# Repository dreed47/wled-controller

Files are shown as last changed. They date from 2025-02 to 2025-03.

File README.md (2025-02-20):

# WLED Controller (ESP32) - 4 Channels - Optional current and power monitoring

## Features

- 4 Channels
  - Max 25A total
  - Max 10A per channel
- Every channel has _independent_ current, power and voltage monitoring (using INA219)
- Sending power monitoring data to HomeAssistant via MQTT
- Seperate 3.3V low noise voltage regulator for audio section
- _**Optional:** INMP441 I2S Microphone with low noise power supply_
- Two versions of PCB esp32 dev kit and esp32 SMD
- This board requires a usermod for WLED for full support of all features including power monitoring.

## ESP32 Dev Kit Version

Interactive [BOM can be found here](https://rawcdn.githack.com/dreed47/wled-controller/main/bom/ibom.html).

### 3D Board view

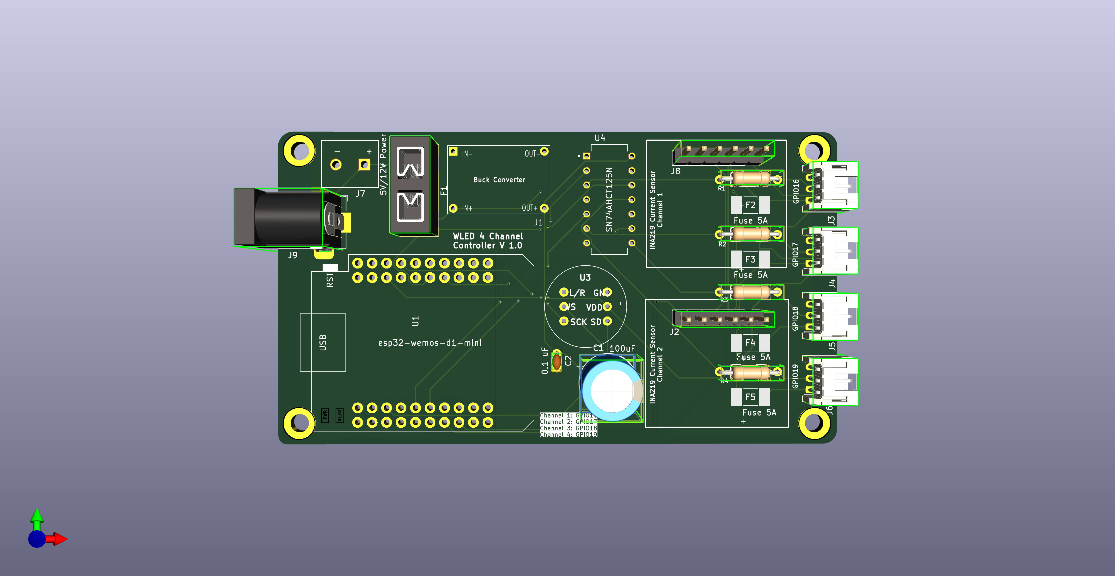
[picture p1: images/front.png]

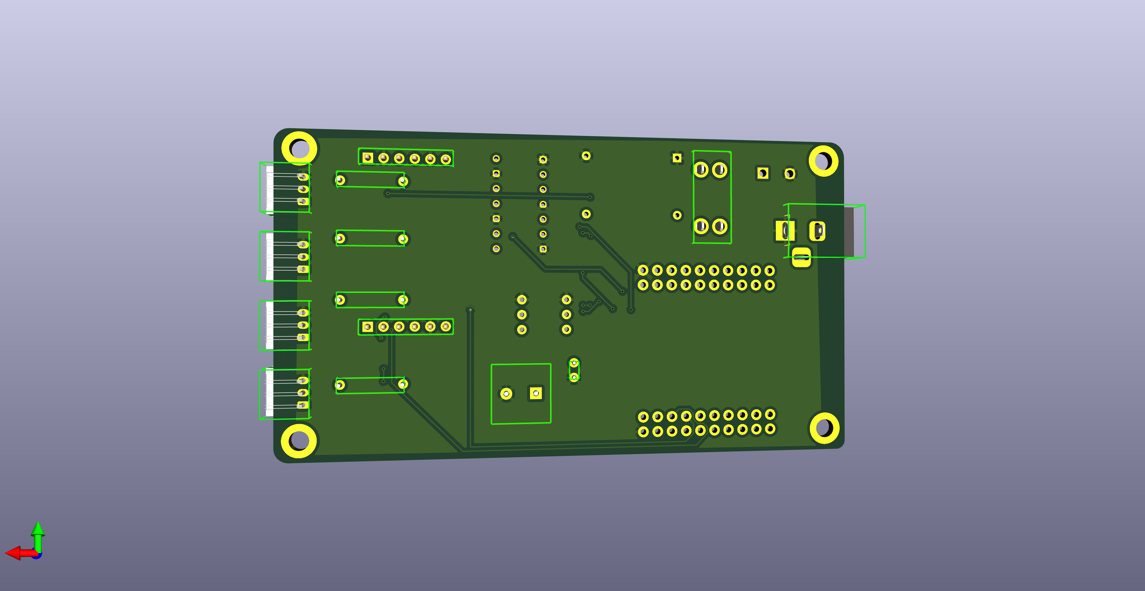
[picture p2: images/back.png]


### Board

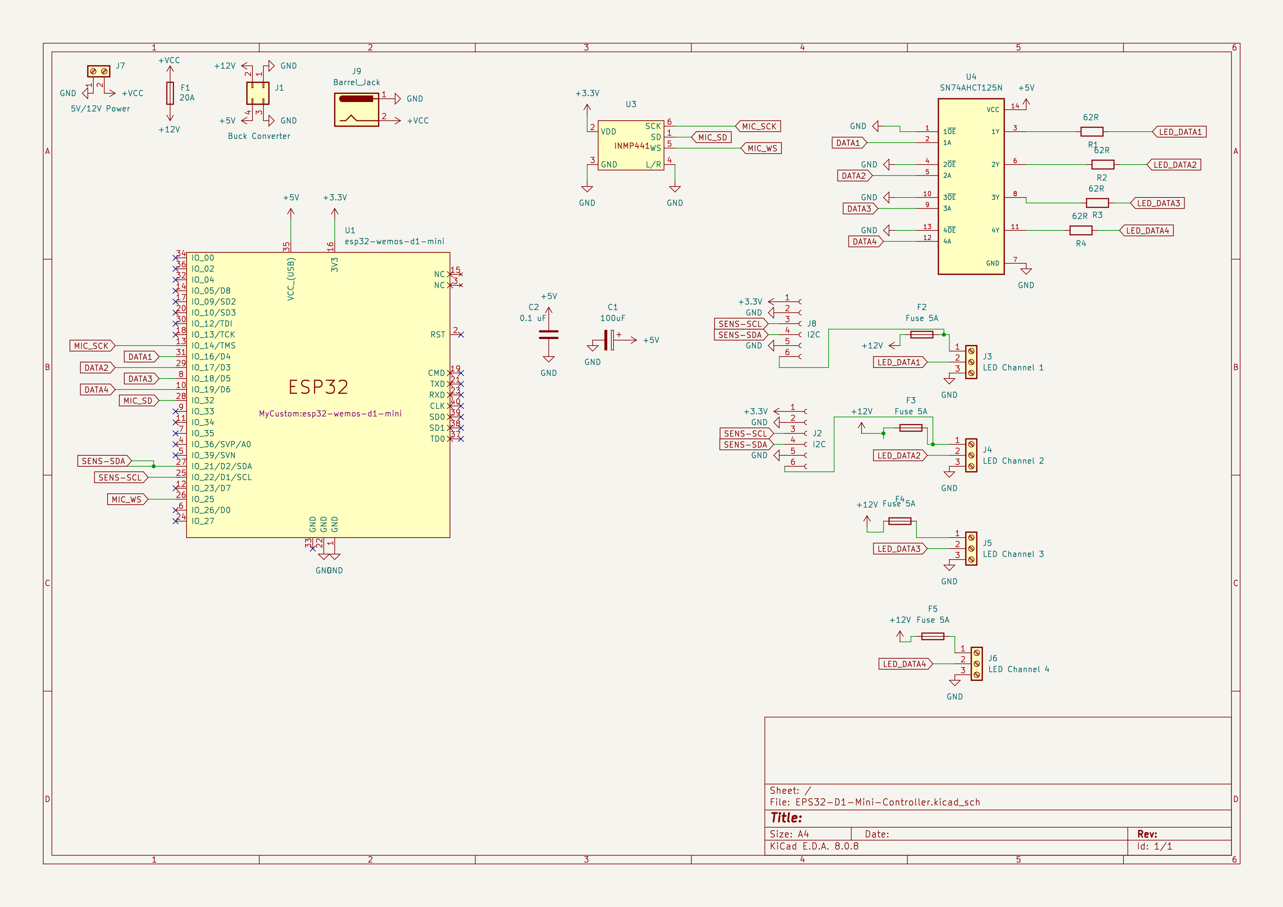
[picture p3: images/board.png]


## ESP32 SMD Version

Interactive [BOM can be found here](https://rawcdn.githack.com/dreed47/wled-controller/main/bom_smd/ibom.html).

### 3D Board view

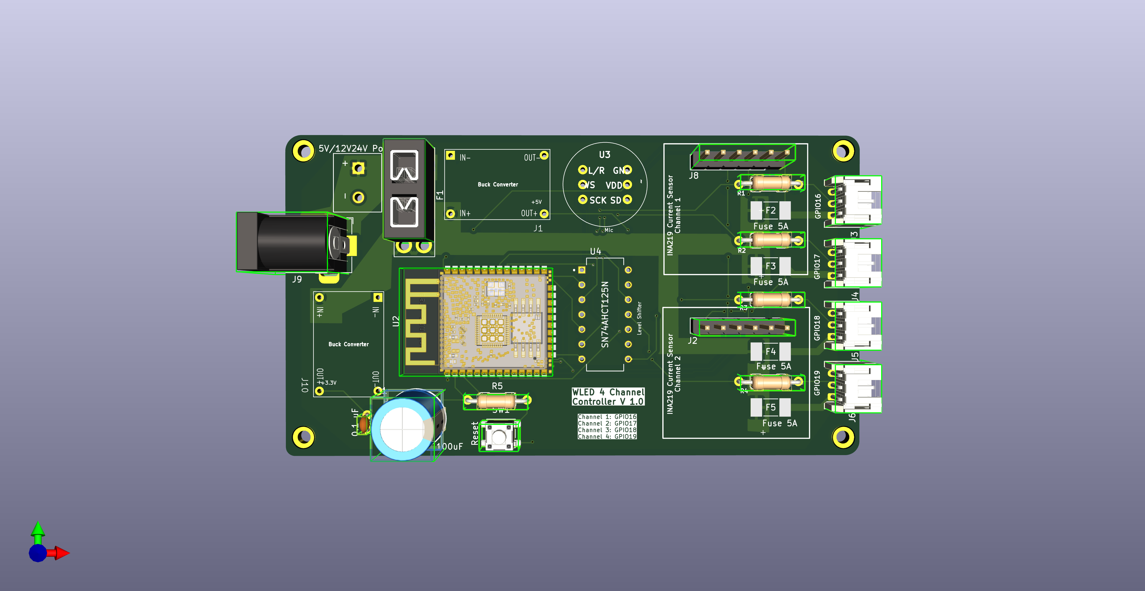
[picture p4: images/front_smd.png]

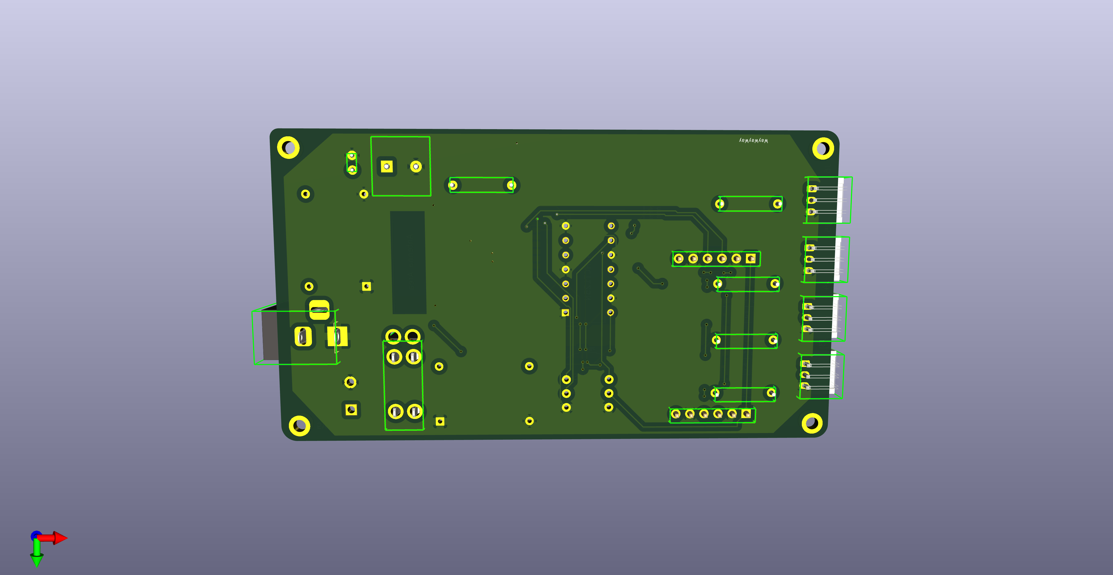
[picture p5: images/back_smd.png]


### Board

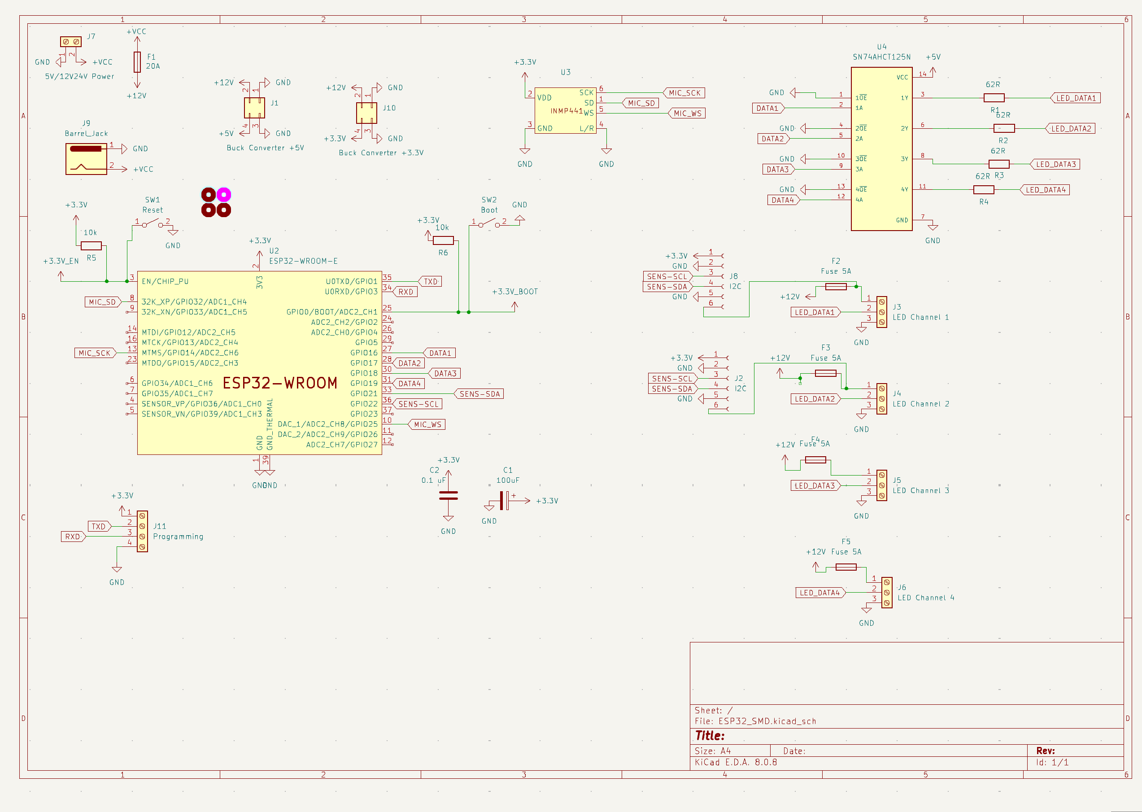
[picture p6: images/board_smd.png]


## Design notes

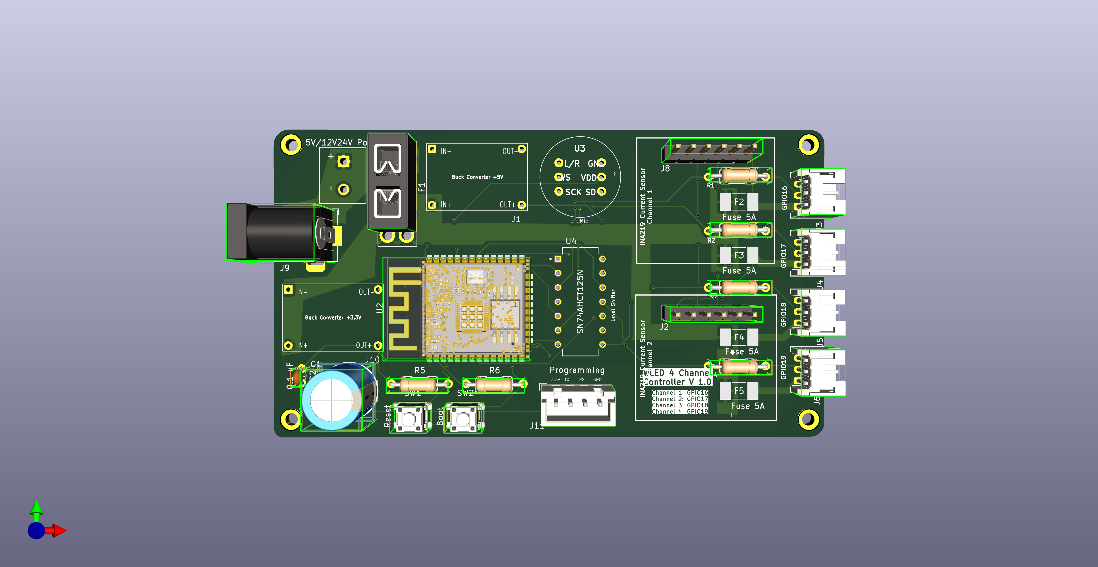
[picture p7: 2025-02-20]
images/ESP32_SMD.png

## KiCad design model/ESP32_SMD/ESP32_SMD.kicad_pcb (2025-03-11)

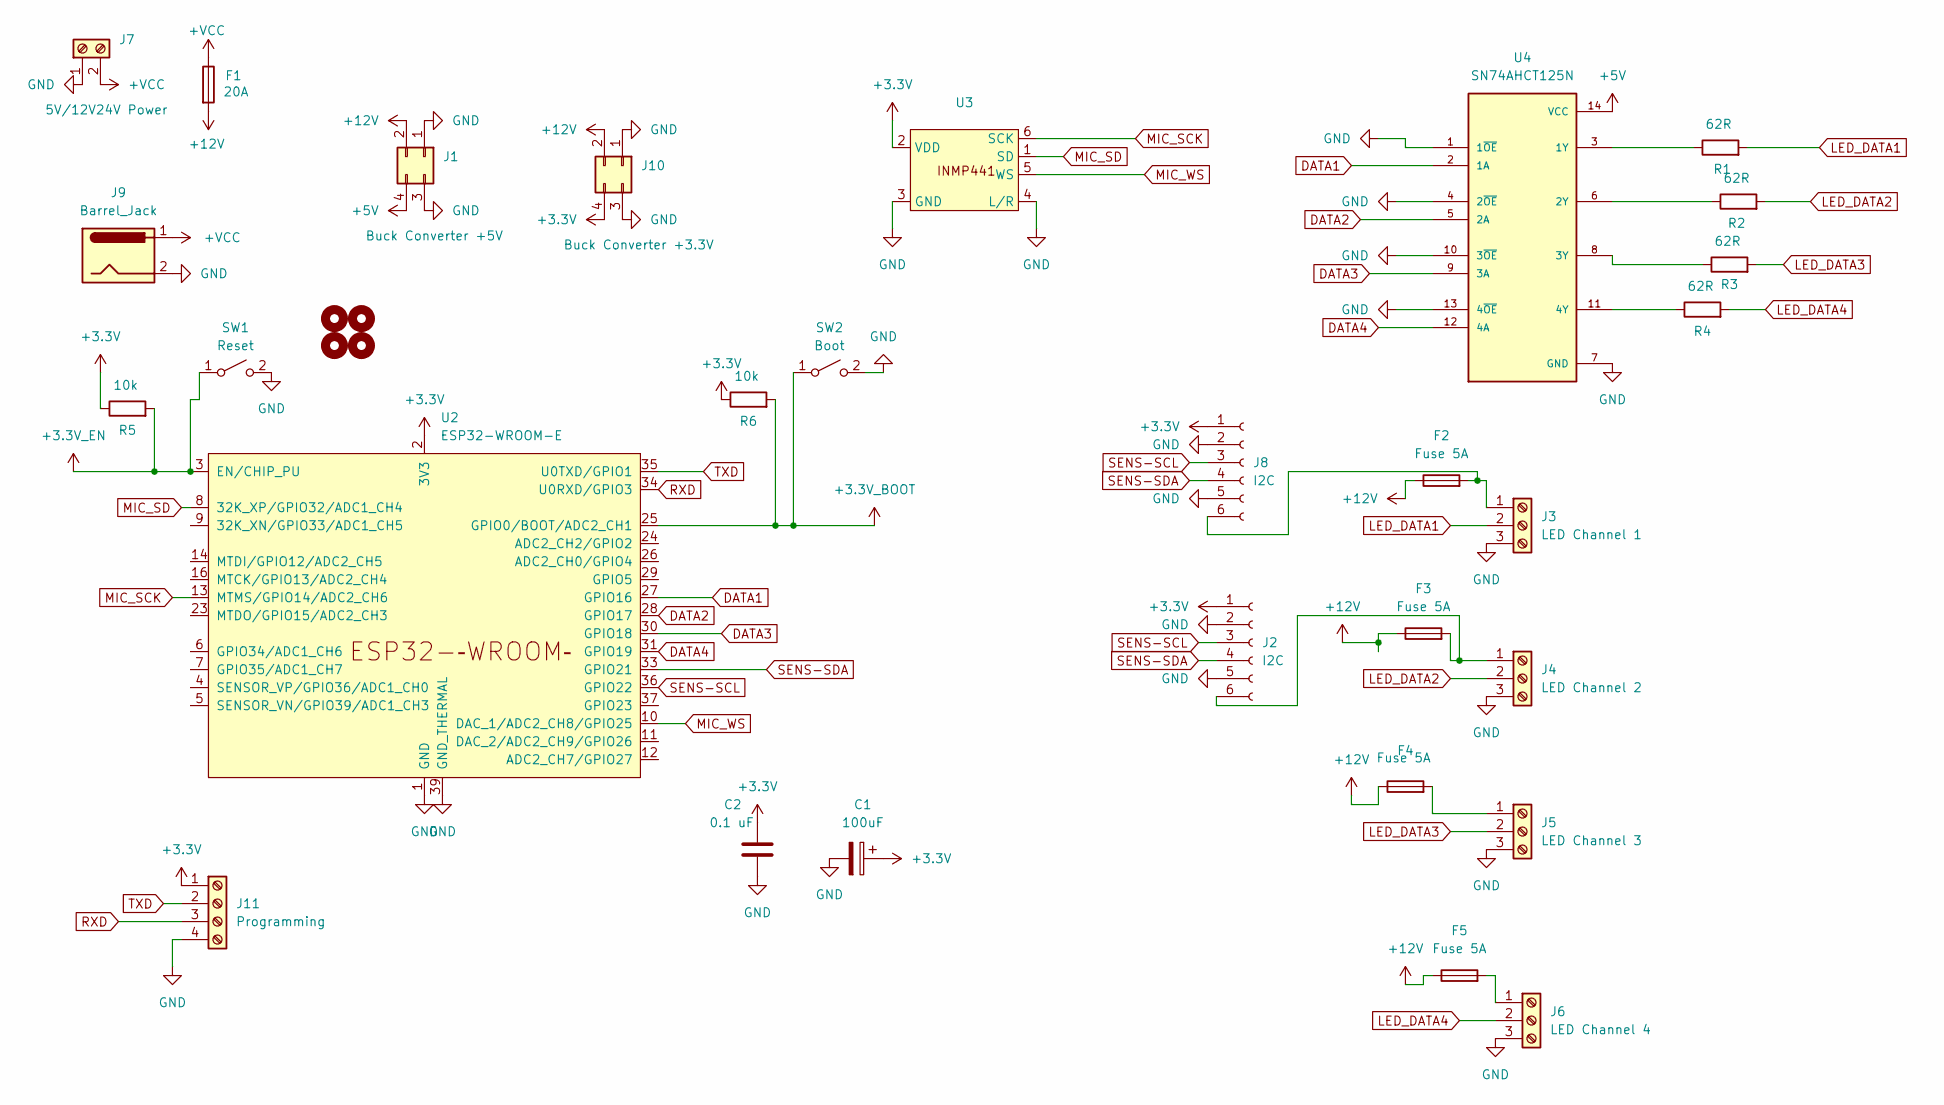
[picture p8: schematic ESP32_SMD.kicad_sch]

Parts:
C1: 100uF; CP_Radial_D10.0mm_P5.00mm
C2: 0.1 uF; C_Disc_D3.0mm_W1.6mm_P2.50mm
F1: 20A; Fuseholder_Blade_Mini_Keystone_3568
F2, F3, F4, F5: Fuse 5A; Fuse_Littelfuse-NANO2-451_453
H1, H2, H3, H4: MountingHole; MountingHole_2.2mm_M2_DIN965_Pad
J1: Buck Converter +5V; Buck Converter Board
J2, J8: I2C; PinHeader_1x06_P2.54mm_Vertical
J3: LED Channel 1; TerminalBlock_Phoenix_MPT-0,5-3-2.54_1x03_P2.54mm_Horizontal
J4: LED Channel 2; TerminalBlock_Phoenix_MPT-0,5-3-2.54_1x03_P2.54mm_Horizontal
J5: LED Channel 3; TerminalBlock_Phoenix_MPT-0,5-3-2.54_1x03_P2.54mm_Horizontal
J6: LED Channel 4; TerminalBlock_Phoenix_MPT-0,5-3-2.54_1x03_P2.54mm_Horizontal
J7: 5V/12V24V Power; PHOENIX_1935161
J9: Barrel_Jack; BarrelJack_Horizontal
J10: Buck Converter +3.3V; Buck Converter Board
J11: Programming; JST_XH_B4B-XH-A_1x04_P2.50mm_Vertical
R1, R2, R3, R4: 62R; R_Axial_DIN0207_L6.3mm_D2.5mm_P10.16mm_Horizontal
R5, R6: 10k; R_Axial_DIN0207_L6.3mm_D2.5mm_P10.16mm_Horizontal
SW1: Reset; SW_SPST_PTS647_Sx38
SW2: Boot; SW_SPST_PTS647_Sx38
U2: ESP32-WROOM-E; ESP32-WROOM-32E
U3: INMP441_Module
U4: SN74AHCT125N; DIP794W45P254L1930H508Q14; PARTREV Q; DigiKey_Part_Number 2156-SN74AHCT125N-ND

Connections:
+3.3V: C1.1, C2.1, J2.1, J8.1, J10.4, J11.1, R5.1, R6.1, U2.2 (3V3), U3.2 (VDD)
+3.3V_BOOT: R6.2, SW2.1 (A), U2.25 (GPIO0/BOOT/ADC2_CH1)
+3.3V_EN: R5.2, SW1.1 (A), U2.3 (EN/CHIP_PU)
+5V: J1.4, U4.14 (VCC)
+12V: F1.2, F2.1, F3.1, F4.1, F5.1, J1.2, J10.2
+VCC: F1.1, J7.2, J9.1
DATA1: U2.27 (GPIO16), U4.2 (1A)
DATA2: U2.28 (GPIO17), U4.5 (2A)
DATA3: U2.30 (GPIO18), U4.9 (3A)
DATA4: U2.31 (GPIO19), U4.12 (4A)
GND: C1.2, C2.2, J1.1, J1.3, J2.2, J2.5, J3.3, J4.3, J5.3, J6.3, J7.1, J8.2, J8.5, J9.2, J10.1, J10.3, J11.4, SW1.2 (B), SW2.2 (B), U2.1 (GND), U2.15 (GND), U2.38 (GND), U2.39 (GND_THERMAL), U3.3 (GND), U3.4 (L/R), U4.1 (1~OE), U4.4 (2~OE), U4.7 (GND), U4.10 (3~OE), U4.13 (4~OE)
LED_DATA1: J3.2, R1.2
LED_DATA2: J4.2, R2.2
LED_DATA3: J5.2, R3.2
LED_DATA4: J6.2, R4.2
MIC_SCK: U2.13 (MTMS/GPIO14/ADC2_CH6), U3.6 (SCK)
MIC_SD: U2.8 (32K_XP/GPIO32/ADC1_CH4), U3.1 (SD)
MIC_WS: U2.10 (DAC_1/ADC2_CH8/GPIO25), U3.5 (WS)
unnamed: F3.2, J2.6, J4.1
unnamed: F2.2, J3.1, J8.6
unnamed: F4.2, J5.1
unnamed: F5.2, J6.1
unnamed: R1.1, U4.3 (1Y)
unnamed: R2.1, U4.6 (2Y)
unnamed: R3.1, U4.8 (3Y)
unnamed: R4.1, U4.11 (4Y)
RXD: J11.3, U2.34 (U0RXD/GPIO3)
SENS-SCL: J2.3, J8.3, U2.36 (GPIO22)
SENS-SDA: J2.4, J8.4, U2.33 (GPIO21)
TXD: J11.2, U2.35 (U0TXD/GPIO1)

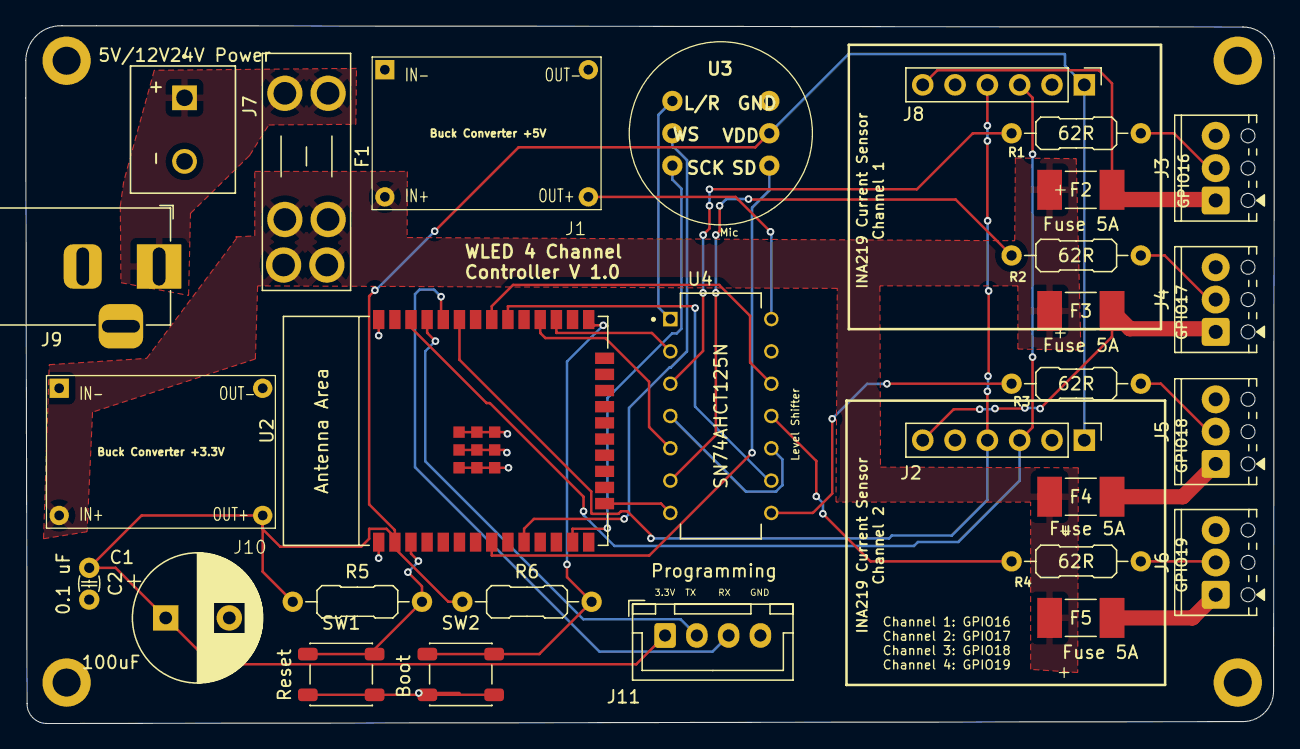
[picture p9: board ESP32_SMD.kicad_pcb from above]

Board: 2 copper layers, 98.2 x 54.9 mm, 33 parts (0 on the bottom side), 30 nets.

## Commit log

2025-03-09 fixed barrel jack
    [ESP32_SMD.kicad_pcb, ESP32_SMD.kicad_sch]
2025-03-09 fix barrell jack
    [EPS32-D1-Mini-Controller.kicad_pcb, EPS32-D1-Mini-Controller.kicad_sch]
